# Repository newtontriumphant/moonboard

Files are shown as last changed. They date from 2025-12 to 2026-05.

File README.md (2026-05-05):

# moonboard, by zsharpminor!

Hi there and welcome! This is moonboard - a custom RP2040-powered devboard with an integrated temperature sensor and a status LED. Surprisingly, it's fully functional first-attempt and isn't (yet!) acting as a hot plate.

# Design:

I made this project to get experience wiring tight spaces in KiCad - my first time wiring a non-premade MCU.

### Schematic

Screenshot 2025-12-09 at 7 22 29 PM

### PCB

Screenshot 2025-12-09 at 7 23 00 PM

(front)

Screenshot 2025-12-09 at 7 23 13 PM

(back)

Screenshot 2025-12-09 at 7 23 29 PM

(silkscreen front)

Screenshot 2025-12-09 at 7 23 47 PM

(silkscreen back)

### 3D RENDERS OF PCB

Screenshot 2025-12-09 at 7 24 34 PM

(front)

Screenshot 2025-12-09 at 7 25 03 PM

(back)

### JLCPCB IMAGES:

Screenshot 2025-12-26 at 4 31 39 PM
Screenshot 2025-12-26 at 4 17 21 PM
Screenshot 2025-12-26 at 4 11 20 PM
Screenshot 2025-12-26 at 4 07 55 PM

**LINK TO ONLINE BOM**: https://docs.google.com/spreadsheets/d/1HLCWrT6yZXuZGsytFHmTzsnE9zg9GKQJlMwihE3njsE/

(BOM.csv file also attached in PCB folder).

# Build:

**A video demo of the completed build can be found here:** https://youtube.com/shorts/RiM_gK4lOYQ



(front!!)



(back ;w;)



(bootloader working first try!!)



(test board working!! yay!!)



(simple boring polyrhythm test code!!)

Thanks for reading up to here, you get a cookie! 🍪 :D

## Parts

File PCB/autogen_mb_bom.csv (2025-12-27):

Id | Designator | Footprint | Quantity | Designation | Supplier and ref
1 | C17,C11,C8,C3,C9,C4,C1,C7,C6,C12,C5 | C_0402_1005Metric | 11 | .1uF
2 | C16,C15 | C_0402_1005Metric | 2 | 33pF
3 | J1 | USB_C_Receptacle_HRO_TYPE-C-31-M-12 | 1 | USB_C_Receptacle_USB2.0_14P
4 | U4 | SOT-23 | 1 | MCP9700Ax-ETT
5 | U2 | SOT-23 | 1 | MCP1700x-330xxTT
6 | C18 | C_0402_1005Metric | 1 | 0.1 uF
7 | J3,J2 | PinHeader_1x20_P2.54mm_Vertical | 2 | Conn_01x20
8 | R8,R2,R7 | R_0402_1005Metric | 3 | 1K
9 | C10,C2 | C_0402_1005Metric | 2 | 1uF
10 | U3 | Winbond_USON-8-1EP_3x2mm_P0.5mm_EP0.2x1.6mm | 1 | W25Q16JVSS
11 | C14,C13 | C_0402_1005Metric | 2 | 10uF
12 | D1 | LED_SK6812MINI_PLCC4_3.5x3.5mm_P1.75mm | 1 | SK6812MINI
13 | R5,R4 | R_0402_1005Metric | 2 | 27
14 | J4 | PinHeader_1x03_P2.54mm_Vertical | 1 | Conn_01x03
15 | Y1 | Crystal_SMD_3225-4Pin_3.2x2.5mm | 1 | 12 MHz
16 | R3,R1 | R_0402_1005Metric | 2 | 5.1K
17 | SW1 | SW_Push_SPST_NO_Alps_SKRK | 1 | SW_Push
18 | U1 | QFN-56-1EP_7x7mm_P0.4mm_EP3.2x3.2mm | 1 | RP2040
19 | R6 | R_0402_1005Metric | 1 | 10K

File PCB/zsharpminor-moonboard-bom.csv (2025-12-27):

JLCPCB BOM Tool - BOM Matching
 |  |  | Download Time：2025-12-26 10:21:17
PCB Assembled Qty：2 |  |  | Est. Total Price：11.6020
 |  |  |  | Matched Parts |  |  |  |  |  | Order Information
Top Designator | Bottom Designator | Comment | Footprint | Matches | Part # | Manufacturer | Footprint | Description | Category | JLCPCB Part # | Product link | Lib Type | Qty | Source | Total Price ($)
C1,C10 |  | 1uF | C_0402_1005Metric | Select by Customer | CL05A105KA5NQNC | Samsung Electro-Mechanics | 402 | 1uF 25V X5R ±10% 0402 Multilayer Ceramic Capacitors MLCC - SMD/SMT ROHS | Multilayer Ceramic Capacitors MLCC - SMD/SMT | C52923 | https://jlcpcb.com/partdetail/53938-CL05A105KA5NQNC/C52923 | Basic | 10 | 10 JLCPCB | 0.029
C8,C6,C5,C4,C2,C7,C11,C9,C12,C17,C3 |  | 0.1uF | C_0402_1005Metric | Select by Customer | CL05B104KO5NNNC | Samsung Electro-Mechanics | 402 | 100nF 16V X7R ±10% 0402 Multilayer Ceramic Capacitors MLCC - SMD/SMT ROHS | Multilayer Ceramic Capacitors MLCC - SMD/SMT | C1525 | https://jlcpcb.com/partdetail/1877-CL05B104KO5NNNC/C1525 | Basic | 55 | 55 JLCPCB | 0.0605
C13,C14 |  | 10uF | C_0603_1608Metric | Select by System | CL10A106KP8NNNC | Samsung Electro-Mechanics | 603 | 10V 10uF X5R ±10% 0603 Multilayer Ceramic Capacitors MLCC - SMD/SMT ROHS | Multilayer Ceramic Capacitors MLCC - SMD/SMT | C19702 | https://jlcpcb.com/partdetail/20411-CL10A106KP8NNNC/C19702 | Basic | 10 | 10 JLCPCB | 0.056
C16,C15 |  | 33pF | C_0402_1005Metric | Select by Customer | 0402CG330J500NT | FH (Guangdong Fenghua Advanced Tech) | 402 | 33pF 50V C0G ±5% 0402 Multilayer Ceramic Capacitors MLCC - SMD/SMT ROHS | Multilayer Ceramic Capacitors MLCC - SMD/SMT | C1562 | https://jlcpcb.com/partdetail/1914-0402CG330J500NT/C1562 | Basic | 10 | 10 JLCPCB | 0.01
J1 |  | USB_C_Receptacle_USB2.0_14P | USB_C_Receptacle_HRO_TYPE-C-31-M-12 | Select by Customer | TYPE-C-31-M-12 | Korean Hroparts Elec | SMD | 1 16P 5A Female Type-C SMD USB Connectors ROHS | USB Connectors | C165948 | https://jlcpcb.com/partdetail/Korean_HropartsElec-TYPE_C_31_M12/C165948 | Extended | 5 | 5 JLCPCB | 0.8445
J3,J2 |  | Conn_01x20 | PinHeader_1x20_P2.54mm_Vertical | Select by Customer | 2.54-1*20P直针 | BOOMELE(Boom Precision Elec) | 插件,P=2.54mm | -40℃~+105℃ 1 1x20P 2.54mm 20P 3A Black Brass Pin Header Through Hole Plugin,P=2.54mm Pin Headers ROHS | Pin Headers | C50981 | https://jlcpcb.com/partdetail/51993-2_54_1_20P/C50981 | Extended | 0 | 0 JLCPCB | 0
J4 |  | Conn_01x03 | PinHeader_1x03_P2.54mm_Vertical | Select by Customer | 1.27-1*3P针 | BOOMELE(Boom Precision Elec) | 插件,P=1.27mm | -55℃~+105℃ 1 1.27mm 1mm 1x3P 2.3mm 3A 3P 3mm Black Brass Pin Header Through Hole Plugin,P=1.27mm Pin Headers ROHS | Pin Headers | C24980 | https://jlcpcb.com/partdetail/25717-1_27_1_3P/C24980 | Extended | 0 | 0 JLCPCB | 0
R2,R1 |  | 5.1K | R_0402_1005Metric | Select by Customer | 0402WGF5101TCE | UNI-ROYAL(Uniroyal Elec) | 402 | -55℃~+155℃ 5.1kΩ 50V 62.5mW Thick Film Resistor ±1% ±100ppm/℃ 0402 Chip Resistor - Surface Mount ROHS | Chip Resistor - Surface Mount | C25905 | https://jlcpcb.com/partdetail/26648-0402WGF5101TCE/C25905 | Basic | 10 | 10 JLCPCB | 0.005
R3,R4 |  | 27 | R_0402_1005Metric | Select by Customer | 0402WGF270JTCE | UNI-ROYAL(Uniroyal Elec) | 402 | -55℃~+155℃ 27Ω 50V 62.5mW Thick Film Resistor ±1% ±100ppm/℃ 0402 Chip Resistor - Surface Mount ROHS | Chip Resistor - Surface Mount | C25100 | https://jlcpcb.com/partdetail/25843-0402WGF270JTCE/C25100 | Extended | 22 | 22 JLCPCB | 0.011
R6,R5 |  | 1K | R_0402_1005Metric | Select by Customer | 0402WGF1001TCE | UNI-ROYAL(Uniroyal Elec) | 402 | -55℃~+155℃ 1kΩ 50V 62.5mW Thick Film Resistor ±1% ±100ppm/℃ 0402 Chip Resistor - Surface Mount ROHS | Chip Resistor - Surface Mount | C11702 | https://jlcpcb.com/partdetail/12256-0402WGF1001TCE/C11702 | Basic | 10 | 10 JLCPCB | 0.005
R7 |  | 10K | R_0402_1005Metric | Select by Customer | 0402WGF1002TCE | UNI-ROYAL(Uniroyal Elec) | 402 | -55℃~+155℃ 10kΩ 50V 62.5mW Thick Film Resistor ±1% ±100ppm/℃ 0402 Chip Resistor - Surface Mount ROHS | Chip Resistor - Surface Mount | C25744 | https://jlcpcb.com/partdetail/26487-0402WGF1002TCE/C25744 | Basic | 5 | 5 JLCPCB | 0.0025
SW1 |  | SW_Push | SW_Push_SPST_NO_Alps_SKRK | Select by Customer | TS-1088-AR02016 | XUNPU | SMD,4x3mm | -30℃~+80℃ 1.6N 100,000 Cycles 12V 2mm 3mm 4mm 50mA Black Round Button SMD(SMT) Tab SPST Surface Mount,Vertical Without Bracket SMD,4x3mm Tactile Switches ROHS | Tactile Switches | C720477 | https://jlcpcb.com/partdetail/XUNPU-TS_1088AR02016/C720477 | Basic | 5 | 5 JLCPCB | 0.2115
U1 |  | RP2040 | QFN-56-1EP_7x7mm_P0.4mm_EP3.2x3.2mm | Select by Customer | RP2040 | Raspberry Pi | LQFN-56(7x7) | 12bit 133MHz 30 LQFN-56(7x7) Microcontrollers (MCU/MPU/SOC) ROHS | Microcontrollers (MCU/MPU/SOC) | C2040 | https://jlcpcb.com/partdetail/RaspberryPi-RP2040/C2040 | Extended | 5 | 5 JLCPCB | 5.5275
U2 |  | MCP1700x-330xxTT | SOT-23 | Select by Customer | MCP1700T-3302E/TT | Microchip Tech | SOT-23 | -40℃~+125℃@(Tj) 1 1.6uA 178mV@(250mA) 250mA 3.3V 44dB@(100Hz) 6V Fixed Over Temperature Protection Positive SOT-23 Voltage Regulators - Linear, Low Drop Out (LDO) Regulators ROHS | Voltage Regulators - Linear, Low Drop Out (LDO) Regulators | C39051 | https://jlcpcb.com/partdetail/MicrochipTech-MCP1700T_3302ETT/C39051 | Extended | 5 | 5 JLCPCB | 1.717
U4 |  | W25Q16JVUXIQTR | Winbond_USON-8-1EP_3x2mm_P0.5mm_EP0.2x1.6mm | Select by Customer | W25Q16JVUXIQ | Winbond Elec | USON-8-EP(2x3) | 100,000 Cycles 133MHz 16Mbit 2.7V~3.6V 20 Years 3ms SPI USON-8-EP(2x3) NOR FLASH ROHS | NOR FLASH | C2843335 | https://jlcpcb.com/partdetail/WinbondElec-W25Q16JVUXIQ/C2843335 | Extended | 5 | 5 JLCPCB | 2.8
Y1 |  | 12MHz | Crystal_SMD_3225-4Pin_3.2x2.5mm | Select by Customer | X322512MSB4SI | YXC Crystal Oscillators | SMD3225-4P | -40℃~+85℃ 12MHz 20pF Crystal Oscillator ±10ppm ±20ppm SMD3225-4P Crystals ROHS | Crystals | C9002 | https://jlcpcb.com/partdetail/YXC_CrystalOscillators-X322512MSB4SI/C9002 | Basic | 5 | 5 JLCPCB | 0.3225
 |  |  |  |  |  |  |  |  |  |  |  |  |  | PCBA TOTAL | 11.602
OTHER COSTS
PCB Production (JLCPCB) | $4.00
PCBA Labor + Extended Parts Cost | $28.10
Shipping (GSDL) | $3.30
Discount from JLCPCB | -$10.00
PRE-PCBA TOTAL: | $25.40
GRAND GRANT TOTAL: | $37.00

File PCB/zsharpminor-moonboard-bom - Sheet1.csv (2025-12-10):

IMPORTANT NOTE: | I am NOT requesting a grant for this project. That's why prices aren't here.
 | This is a project for *tickets* only at the moment.
 | A BOM is included below nevertheless to meet submission guidelines.
Name | Link | Quantity
RP2040 MCU | https://www.lcsc.com/product-detail/C2040.html?s_z=n_rp2040 | 1
W25Q16JVSS | https://www.lcsc.com/product-detail/C131025.html?s_z=n_W25Q16JVSS | 1
USB_C_Receptacle_USB2.0_14P | https://www.lcsc.com/product-detail/C223907.html?s_z=n_C223907 | 1
SK6812MINI | https://www.lcsc.com/product-detail/C5149201.html?s_z=n_SK6812MINI | 1
C_0402_1005Metric (0.1 uF) | https://www.lcsc.com/product-detail/C1525.html?s_z=n_C1525 | 12
C_0402_1005Metric (33 pF) | https://www.lcsc.com/product-detail/C70465.html?s_z=n_C70465 | 2
MCP9700Ax-ETT | https://www.lcsc.com/product-detail/C127949.html?s_z=n_C127949 | 1
MCP1700x-330xxTT | https://www.lcsc.com/product-detail/C39051.html?s_z=n_C39051 | 1
PinHeader_1x20_P2.54mm_Vertical | https://www.lcsc.com/product-detail/C2938459.html?s_z=n_01x20 | 2
PinHeader_1x03_P2.54mm_Vertical | https://www.lcsc.com/product-detail/C52016391.html?s_z=n_pin | 1
R_0402_1005Metric (1K) | https://www.lcsc.com/product-detail/C106235.html?s_z=n_C106235 | 3
C_0402_1005Metric (1 uF) | https://www.lcsc.com/product-detail/C52923.html?s_z=n_C52923 | 2
C_0402_1005Metric (10 uF) | https://www.lcsc.com/product-detail/C15525.html?s_z=n_C15525 | 2
R_0402_1005Metric (27) | https://www.lcsc.com/product-detail/C138021.html?s_z=n_C138021 | 2
Crystal_SMD_3225-4Pin_3.2x2.5mm (12 MHz) | https://www.lcsc.com/product-detail/C9002.html?s_z=n_C9002 | 1
R_0402_1005Metric (5.1K) | https://www.lcsc.com/product-detail/C105872.html?s_z=n_C105872 | 2
SW_Push_SPST_NO_Alps_SKRK | https://www.lcsc.com/product-detail/C202388.html?s_z=n_C202388 | 1
R_0402_1005Metric (10K) | https://www.lcsc.com/product-detail/C60490.html?s_z=n_C60490 | 1
PCBA | https://jlcpcb.com/ | 1
TOTAL GRANT REQUIRED: | $0 USD

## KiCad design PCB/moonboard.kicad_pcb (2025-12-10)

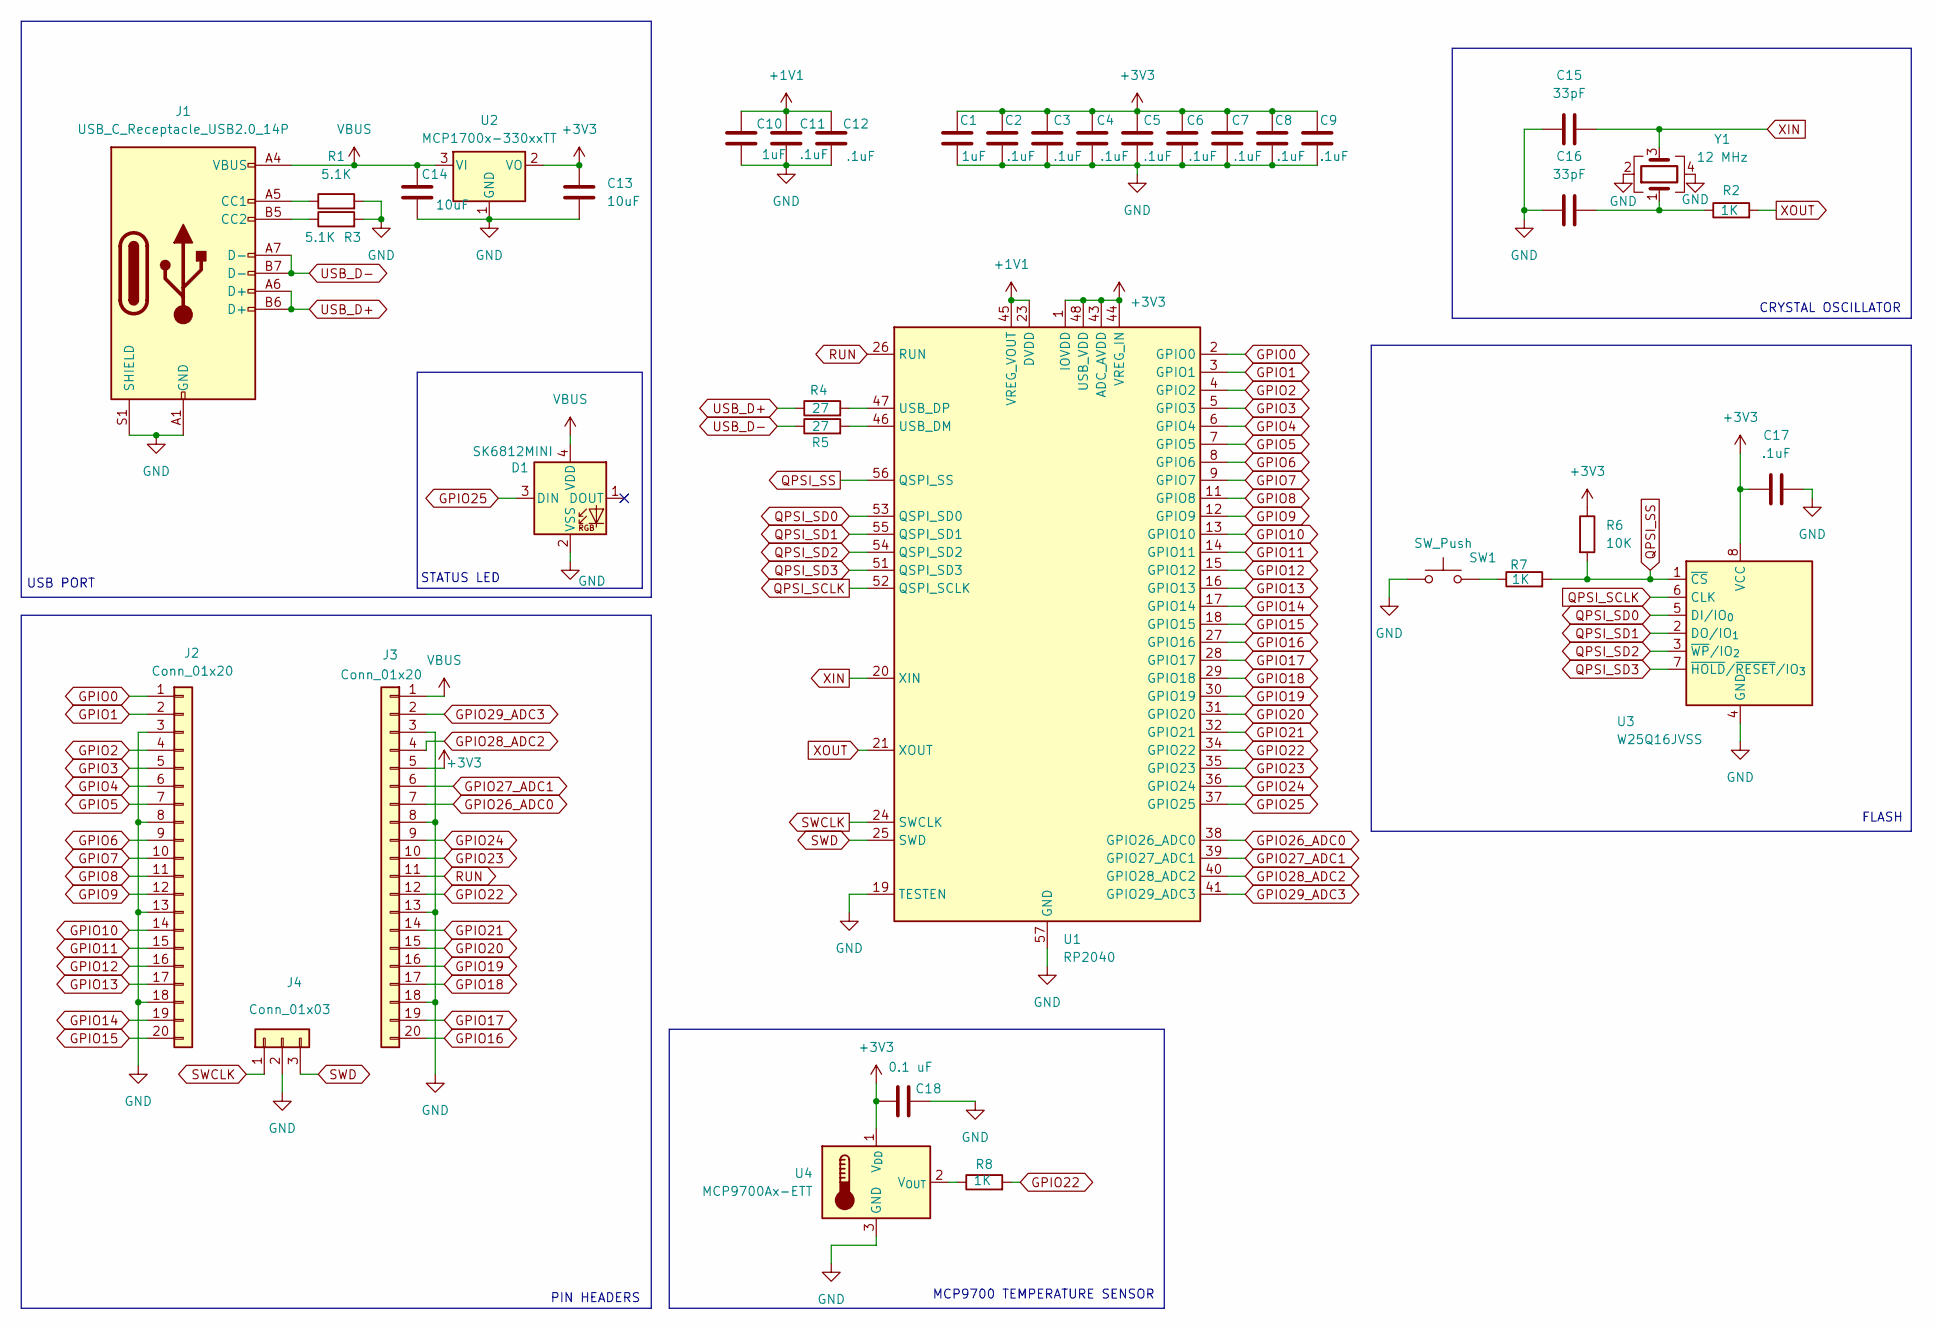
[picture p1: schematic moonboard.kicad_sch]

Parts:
C1, C3, C4, C5, C6, C7, C8, C9, C11, C12, C17: .1uF; C_0402_1005Metric
C2, C10: 1uF; C_0402_1005Metric
C13, C14: 10uF; C_0402_1005Metric
C15, C16: 33pF; C_0402_1005Metric
C18: 0.1 uF; C_0402_1005Metric
D1: SK6812MINI; LED_SK6812MINI_PLCC4_3.5x3.5mm_P1.75mm
J1: USB_C_Receptacle_USB2.0_14P; USB_C_Receptacle_HRO_TYPE-C-31-M-12
J2, J3: Conn_01x20; PinHeader_1x20_P2.54mm_Vertical
J4: Conn_01x03; PinHeader_1x03_P2.54mm_Vertical
R1, R3: 5.1K; R_0402_1005Metric
R2, R7, R8: 1K; R_0402_1005Metric
R4, R5: 27; R_0402_1005Metric
R6: 10K; R_0402_1005Metric
SW1: SW_Push; SW_Push_SPST_NO_Alps_SKRK
U1: RP2040; QFN-56-1EP_7x7mm_P0.4mm_EP3.2x3.2mm
U2: MCP1700x-330xxTT; SOT-23
U3: W25Q16JVSS; Winbond_USON-8-1EP_3x2mm_P0.5mm_EP0.2x1.6mm
U4: MCP9700Ax-ETT; SOT-23
Y1: 12 MHz; Crystal_SMD_3225-4Pin_3.2x2.5mm

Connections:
+1V1: C10.1, C11.1, C12.1, U1.23 (DVDD), U1.45 (VREG_VOUT), U1.50 (DVDD)
+3V3: C1.1, C2.1, C3.1, C4.1, C5.1, C6.1, C7.1, C8.1, C9.1, C13.1, C17.1, C18.1, J3.5, R6.1, U1.1 (IOVDD), U1.10 (IOVDD), U1.22 (IOVDD), U1.33 (IOVDD), U1.42 (IOVDD), U1.43 (ADC_AVDD), U1.44 (VREG_IN), U1.48 (USB_VDD), U1.49 (IOVDD), U2.2 (VO), U3.8 (VCC), U4.1 (V_{DD})
GND: C1.2, C2.2, C3.2, C4.2, C5.2, C6.2, C7.2, C8.2, C9.2, C10.2, C11.2, C12.2, C13.2, C14.2, C15.1, C16.1, C17.2, C18.2, D1.2 (VSS), J1.A1 (GND), J1.A12 (GND), J1.B1 (GND), J1.B12 (GND), J1.S1 (SHIELD), J2.3, J2.8, J2.13, J2.18, J3.3, J3.8, J3.13, J3.18, J4.2, R1.2, R3.2, SW1.1, U1.19 (TESTEN), U1.57 (GND), U2.1 (GND), U3.4 (GND), U4.3 (GND), Y1.2, Y1.4
GPIO0: J2.1, U1.2 (GPIO0)
GPIO1: J2.2, U1.3 (GPIO1)
GPIO2: J2.4, U1.4 (GPIO2)
GPIO3: J2.5, U1.5 (GPIO3)
GPIO4: J2.6, U1.6 (GPIO4)
GPIO5: J2.7, U1.7 (GPIO5)
GPIO6: J2.9, U1.8 (GPIO6)
GPIO7: J2.10, U1.9 (GPIO7)
GPIO8: J2.11, U1.11 (GPIO8)
GPIO9: J2.12, U1.12 (GPIO9)
GPIO10: J2.14, U1.13 (GPIO10)
GPIO11: J2.15, U1.14 (GPIO11)
GPIO12: J2.16, U1.15 (GPIO12)
GPIO13: J2.17, U1.16 (GPIO13)
GPIO14: J2.19, U1.17 (GPIO14)
GPIO15: J2.20, U1.18 (GPIO15)
GPIO16: J3.20, U1.27 (GPIO16)
GPIO17: J3.19, U1.28 (GPIO17)
GPIO18: J3.17, U1.29 (GPIO18)
GPIO19: J3.16, U1.30 (GPIO19)
GPIO20: J3.15, U1.31 (GPIO20)
GPIO21: J3.14, U1.32 (GPIO21)
GPIO22: J3.12, R8.2, U1.34 (GPIO22)
GPIO23: J3.10, U1.35 (GPIO23)
GPIO24: J3.9, U1.36 (GPIO24)
GPIO25: D1.3 (DIN), U1.37 (GPIO25)
GPIO26_ADC0: J3.7, U1.38 (GPIO26_ADC0)
GPIO27_ADC1: J3.6, U1.39 (GPIO27_ADC1)
GPIO28_ADC2: J3.4, U1.40 (GPIO28_ADC2)
GPIO29_ADC3: J3.2, U1.41 (GPIO29_ADC3)
unnamed: C16.2, R2.1, Y1.1
unnamed: J1.A5 (CC1), R1.1
unnamed: J1.B5 (CC2), R3.1
unnamed: R7.1, SW1.2
unnamed: R5.2, U1.46 (USB_DM)
unnamed: R4.2, U1.47 (USB_DP)
unnamed: R8.1, U4.2 (V_{OUT})
QPSI_SCLK: U1.52 (QSPI_SCLK), U3.6 (CLK)
QPSI_SD0: U1.53 (QSPI_SD0), U3.5 (DI/IO_{0})
QPSI_SD1: U1.55 (QSPI_SD1), U3.2 (DO/IO_{1})
QPSI_SD2: U1.54 (QSPI_SD2), U3.3 (~WP/IO_{2})
QPSI_SD3: U1.51 (QSPI_SD3), U3.7 (~HOLD/~RESET/IO_{3})
QPSI_SS: R6.2, R7.2, U1.56 (QSPI_SS), U3.1 (~CS)
RUN: J3.11, U1.26 (RUN)
SWCLK: J4.1, U1.24 (SWCLK)
SWD: J4.3, U1.25 (SWD)
USB_D+: J1.A6 (D+), J1.B6 (D+), R4.1
USB_D-: J1.A7 (D-), J1.B7 (D-), R5.1
VBUS: C14.1, D1.4 (VDD), J1.A4 (VBUS), J1.A9 (VBUS), J1.B4 (VBUS), J1.B9 (VBUS), J3.1, U2.3 (VI)
XIN: C15.2, U1.20 (XIN), Y1.3
XOUT: R2.2, U1.21 (XOUT)

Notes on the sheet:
MCP9700 TEMPERATURE SENSOR
USB PORT
PIN HEADERS
STATUS LED
FLASH
CRYSTAL OSCILLATOR

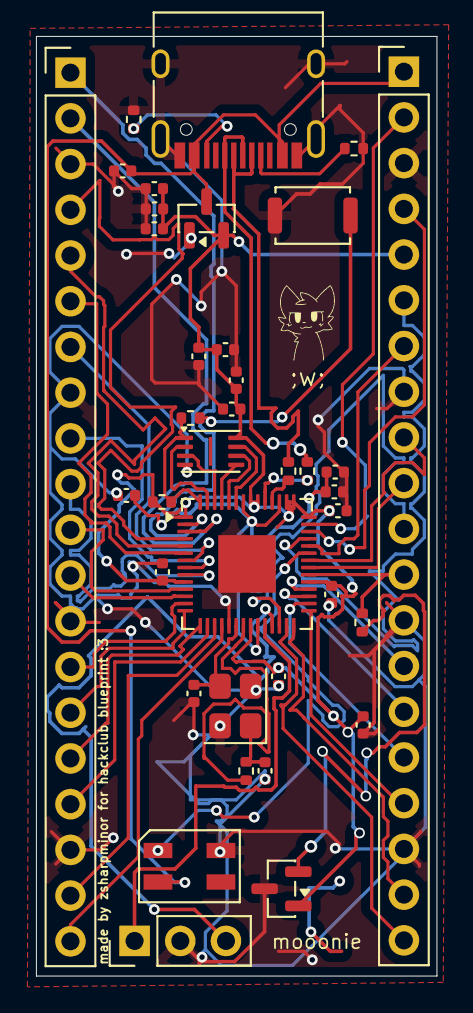
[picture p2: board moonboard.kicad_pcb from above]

Board: 2 copper layers, 22.2 x 52.2 mm, 37 parts (0 on the bottom side), 54 nets.

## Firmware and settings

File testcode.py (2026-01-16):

# Hi! This is moonboard's favorite rhythm! a 2-against-3 polyrhythm! :D I'm so glad it worked, I hope you enjoy.

import board
import digitalio
import time

red_led = digitalio.DigitalInOut(board.GP24)
red_led.direction = digitalio.Direction.OUTPUT
blue_led = digitalio.DigitalInOut(board.GP23)
blue_led.direction = digitalio.Direction.OUTPUT
red_led.value = False
blue_led.value = False
# Polyrythm parameters
tempo = 1.0
red_period = tempo * 2
blue_period = tempo * 3
start_time = time.monotonic()

while True:
    try:
        current_time = time.monotonic()
        
        if (current_time - start_time) % red_period < 0.1:
            red_led.value = True
        else:
            red_led.value = False
        if (current_time - start_time) % blue_period < 0.1:
            blue_led.value = True
        else:
            blue_led.value = False     
        time.sleep(0.01)
    except Exception as e:
        red_led.value = False
        blue_led.value = False
        print("Error occurred:", e)
        break

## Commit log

2025-12-10 Added PCB
2025-12-10 Added BOM.
    [zsharpminor-moonboard-bom.csv]
2025-12-10 Added KiCad PCB Files.
    [moonboard.kicad_pcb, moonboard.kicad_sch]
2025-12-10 Added Gerbers.
2025-12-27 Added New BOM!
    [zsharpminor-moonboard-bom - BOM_JLCPCB.csv]
2025-12-27 Revise BOM with pricing and update notes
    Updated the BOM to include prices and added a warning about the old BOM.
    [zsharpminor-moonboard-bom_OLD.csv]
2025-12-27 Finalized BOM
    [zsharpminor-moonboard-bom.csv]
2025-12-27 Added PCBA files.
    [autogen_mb_bom.csv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]
